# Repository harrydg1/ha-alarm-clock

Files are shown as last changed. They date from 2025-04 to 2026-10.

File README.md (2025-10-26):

# ha-alarm-clock v2
A fully functional alarm clock for home assistant version 2.
Yes, the enclosure is ugly, but it's still work in progress)
Credit where credit's due: This was possible due to the immense help of BC547, if you know him ;)

This is the PCB of an alarm clock I designed because there is nothing like it on the entire net. At least not as far as I know/found.

The inspiration is a cheap alarm clock that I soldered myself, from Aliexpress that had some nice features... but lacks others. So here is a list of what the goal is:
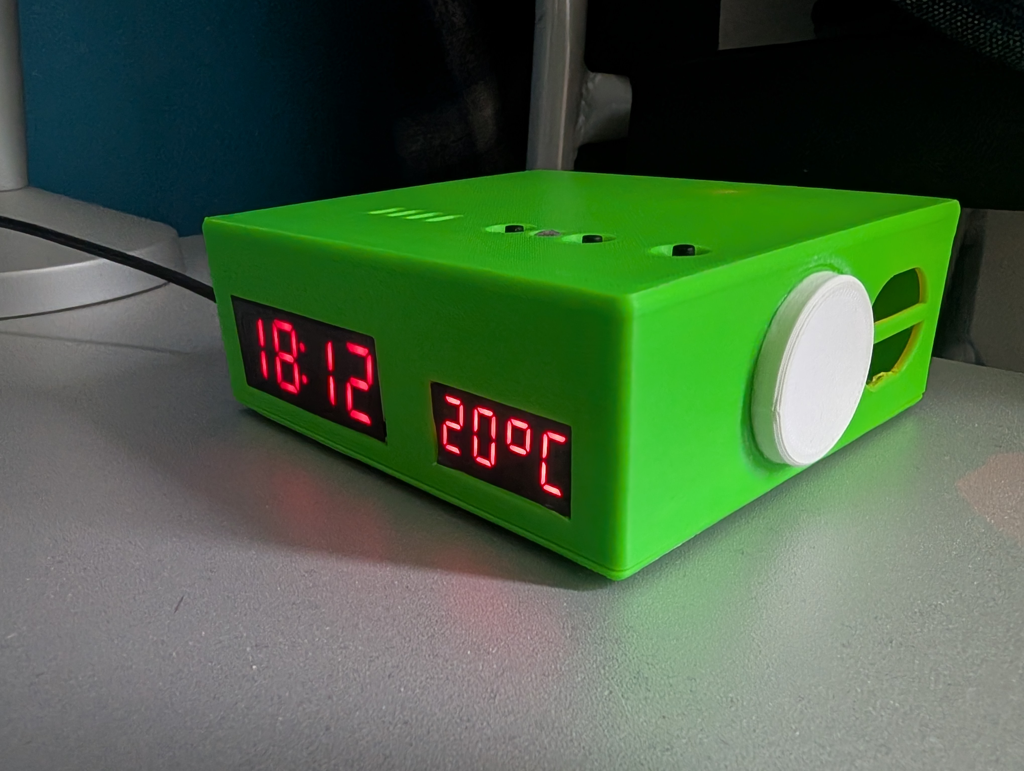
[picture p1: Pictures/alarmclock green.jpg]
picture of the clock

- an alarm clock that you never have to set the time (like daylight saving time, ...), based on the ESP32-S3 chip
- simple good old fashioned red (or any other color you might like) 7 segment display
  - 1 larger one for the time: https://nl.aliexpress.com/item/1005002059351703.html
  - 1 smaller one for the temperature: https://nl.aliexpress.com/item/1005006099563523.html
    for some strange reason the power and gnd on these modules are different on both, so also in my schematic this is the case, it's NOT an error
- with the LDR, this display can be dimmed to not blind you at night, but readable during the day
- 3 buttons, currently in the code: 1 for the LED light, 1 for muting/unmuting the DAC (puts it in very low power mode) and 1 freely configurable in home assistant. Probably I will use it for my curtains.
- a buzzer because it reminds me of the good old nokia phones and you can play the Super Mario Bros tune (if needed you can add a resistor/diode on R7, probably not needed)
- USB-C connector for plenty of power, including ESD protection, impedance maching and all else
- a powerful and high quality voltage regulator (1.2A!)

From bottom, left to right on the PCB
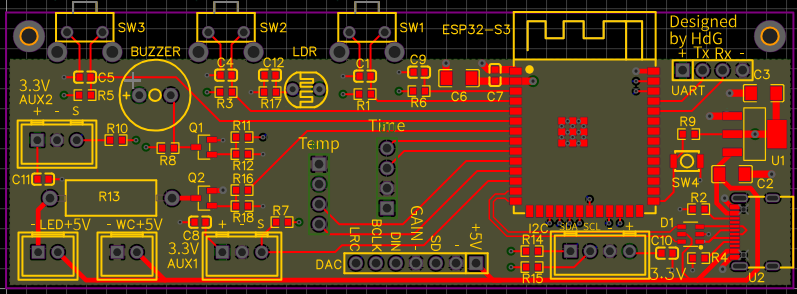
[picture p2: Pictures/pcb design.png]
PCB design

- a built-in high power LED "night light" that is dimmable, with room for a big (2-3W) resistor to limit current if needed: [https://nl.aliexpress.com/item/1005006401939984.html](https://nl.aliexpress.com/item/1005006334229998.html)
- a 5V connector to connect a 5V wireless charging pad: https://nl.aliexpress.com/item/1005005716095383.html
- 2 extra connectors, if you have any ideas what is missing, so it's up to you if you want to add something. PIR maybe? There are 4.7k pull-up resistors forseen
- a DAC + amplifier to play music: https://nl.aliexpress.com/item/1005006711010527.html
  and a speaker to go with the amp, but they are too weak/bad quality: https://nl.aliexpress.com/item/1005007390381560.html
- a connector for I2C where I connected my Bosch BME680, there is also room for a pullup resistor (R13-R14): https://nl.aliexpress.com/item/1005004803087064.html
- (top right): a UART connector, not needed as you can upload via the USB-C connector

The files:
- fusion 360 design file (still needs a lot of improvement, i know!)
- the EasyEDA design files, pictures of the schema and so on are also there
- the yaml code for esphome

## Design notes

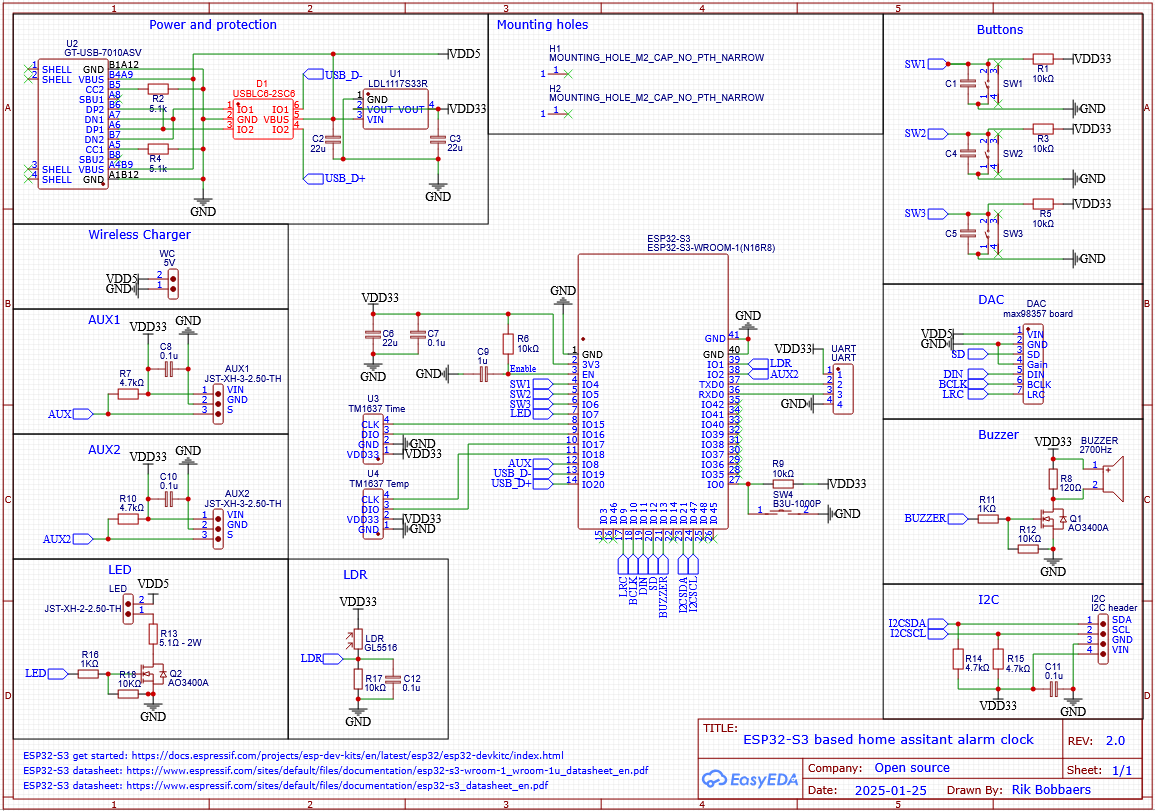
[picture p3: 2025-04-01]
Schematic HA clock.png

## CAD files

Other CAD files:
home assistant alarm clock v9.f3d

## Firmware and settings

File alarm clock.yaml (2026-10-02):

substitutions:
  friendlyname: "alarmclock"
  ha_api_key: !secret home_assistant_api_key
  wifi_ssid: !secret wifi_ssid
  wifi_password: !secret wifi_password
  hotspot_password: !secret hotspot_password

esphome:
  name: ${friendlyname}
  friendly_name: ${friendlyname}
  on_boot:
    then:
      - delay: 5s
      - media_player.volume_set:
         id: slaapkamer_media_player
         volume: 10%

esp32:
  board:   esp32-s3-devkitc-1
  variant: esp32s3
  framework:
    type: esp-idf

psram:
  mode: octal
  speed: 80MHz

# Enable logging
logger:
  level: info

# Enable Home Assistant API
api:
  encryption:
    key: ${ha_api_key}
  actions:
    - action: rtttl_play
      variables:
        song_str: string
      then:
        - rtttl.play:
            rtttl: !lambda 'return song_str;'
#      rtttl.play: 'Flintstones:d=4,o=5,b=200:g#,c#,8p,c#6,8a#,g#,c#,8p,g#,8f#,8f,8f,8f#,8g#,c#,d#,2f,2p,g#,c#,8p,c#6,8a#,g#,c#,8p,g#,8f#,8f,8f,8f#,8g#,c#,d#,2c#'


ota:
  - platform: esphome
    encryption:
      key: ${ha_api_key}

wifi:
  ssid: ${wifi_ssid}
  password: ${wifi_password}

  # Enable fallback hotspot (captive portal) in case wifi connection fails
  ap:
    ssid: "${friendlyname} Fallback Hotspot"
    password: ${hotspot_password}

captive_portal:

globals:
  - id: dim_direction_up
    type: bool
    restore_value: no
    initial_value: 'true'

# AUX1 pin is GPIO8
# AUX2 pin is GPIO2

i2s_audio:
  - id: i2s_out
    i2s_lrclk_pin: GPIO9
    i2s_bclk_pin: GPIO10

speaker:
  - platform: i2s_audio
    id: slaapkamer_speaker
    dac_type: external
    i2s_dout_pin: GPIO11
    channel: mono

media_player:
  - platform: speaker
    name: ${friendlyname} Player
    id: slaapkamer_media_player
    announcement_pipeline:
      speaker: slaapkamer_speaker

i2c:
    sda: GPIO21
    scl: GPIO47

time:
  - platform: sntp
    id: sntp_time
    timezone: Europe/Brussels
    servers:
     - 0.be.pool.ntp.org
     - 1.be.pool.ntp.org
     - 2.be.pool.ntp.org

display:
  - platform: tm1637
    clk_pin: GPIO18
    dio_pin: GPIO17
    inverted: true
    length: 4
    update_interval: 500ms
    intensity: 0
    id: temp_display
    lambda: |-
        it.printf("%.0f~C", id(bedroom_temperature).state);

  - platform: tm1637
    clk_pin: GPIO15
    dio_pin: GPIO16
    update_interval: 500ms
    length: 4
    intensity: 0
    id: time_display
    lambda: |-
        auto t = id(sntp_time).now();
        if (!t.is_valid()) {
          it.print("--.--");
          return;
        }
        int hour = t.hour;
        int minute = t.minute;

        // Blink colon every 2 seconds
        bool blink = (t.second % 2) == 0;

        if (hour < 10) {
          it.printf(" %d%s%02d", hour, blink ? "." : "", minute);
          } else {
          it.printf("%02d%s%02d", hour, blink ? "." : "", minute);
        }

binary_sensor:
  - platform: gpio
    pin:
      number: GPIO4
      inverted: true
      mode:
        input: true
    name: "${friendlyname} Knop Links"
    filters:
      - delayed_on: 10ms
  - platform: gpio
    pin:
      number: GPIO5
      inverted: true
      mode:
        input: true
    name: "${friendlyname} Knop Midden"
    filters:
      - delayed_on: 10ms
  - platform: gpio
    pin:
      number: GPIO6
      inverted: true
      mode:
        input: true
    name: "${friendlyname} Knop Rechts"
    id: knop_rechts
    filters:
      - delayed_on: 10ms
    on_multi_click:
      # 1. DOUBLE CLICK (Must go FIRST)
      - timing:
          - ON for at most 0.4s
          - OFF for at most 0.4s
          - ON for at most 0.4s
        then:
          - logger.log: "Double click"
          - light.turn_on:
              id: bedroomleds
              brightness: 100%

      # 2. SHORT CLICK (Single click)
      - timing:
          - ON for at most 0.7s
          - OFF for at least 0.4s
        then:
          - logger.log: "Simple click"
          - light.toggle: bedroomleds
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

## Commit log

2025-01-18 reorganize folders and add dimming to button
2025-02-19 Updated enclosure and new pictures
    [home assistant alarm clock v9.f3d]
2025-04-03 Update alarm clock.yaml
    error fixed in display
    [alarm clock.yaml]
2025-10-26 Revert "Merge pull request #1 from harrydg1/version-2"
    This reverts commit 6f3c05d956fc4dea09410b8b1669b330f666b94a, reversing
    changes made to bb0289da498f03591a75f0b96be19704c035dd12.
    [alarm clock.yaml]
2025-10-26 Revert "Merge branch 'main' of https://github.com/harrydg1/ha-alarm-clock"
    This reverts commit 8a0ae8884a2c31f576fdb943cdb6a8a26f6e317d, reversing
    changes made to d006edc1407cb8d345c19aaf265a18de03398241.
    [alarm clock.yaml]
